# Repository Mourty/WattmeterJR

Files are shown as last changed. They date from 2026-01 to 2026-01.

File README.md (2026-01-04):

# WattmeterJR

This is a smaller cheaper version of the wattmeter described here https://github.com/Mourty/Wattmeter-Project

This version of the measurment board is greatly different than the original and required seperate firmware, but can interface with the service from the original just fine. This version doesn't have the super capacitor and boost converter. It also forgoes the voltage transformer in favor of a voltage divider. All parts that can be surface mount are. This is to save space and cost. The ESP32 used here also isn't a dev module and doesn't have the normal USB interface and requires a seperate UART programming device.

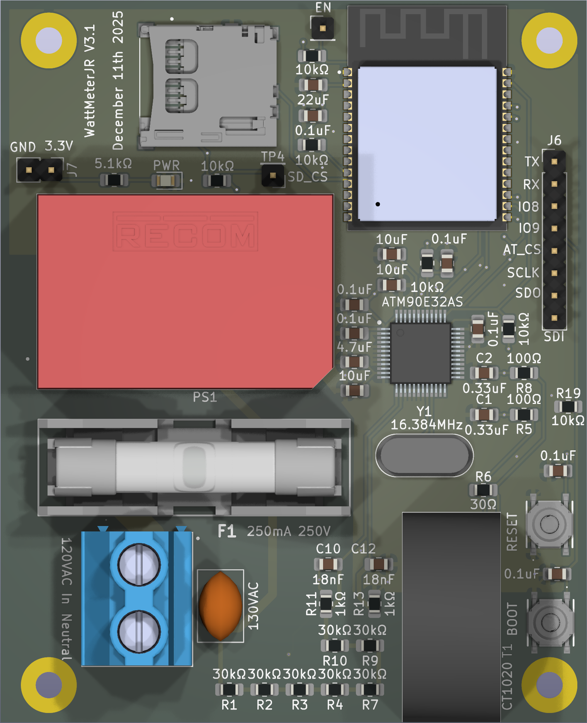
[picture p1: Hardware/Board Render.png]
WattmeterJR Board Render.


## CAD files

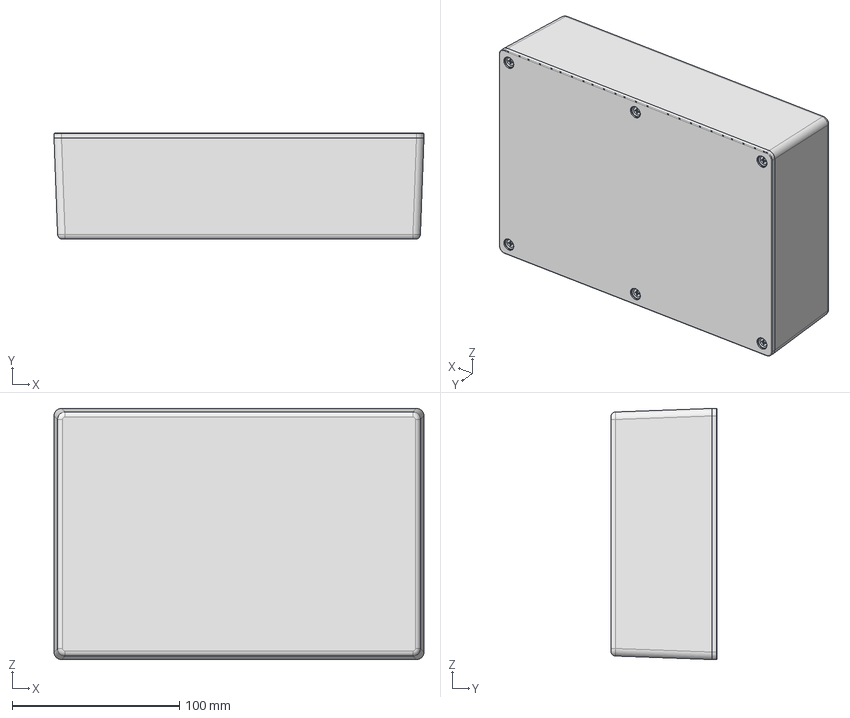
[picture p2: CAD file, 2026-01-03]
Hardware/Circuit and PCB/1591XXFBK.stp
221.0 x 63.5 x 150.0 mm
1591XXF BOX
1591XXF LID
SC500 (screw M3-0.5X 10mm FH) x 6
IN100 (insert M3-0.5X5.75mm BRASS) x 6

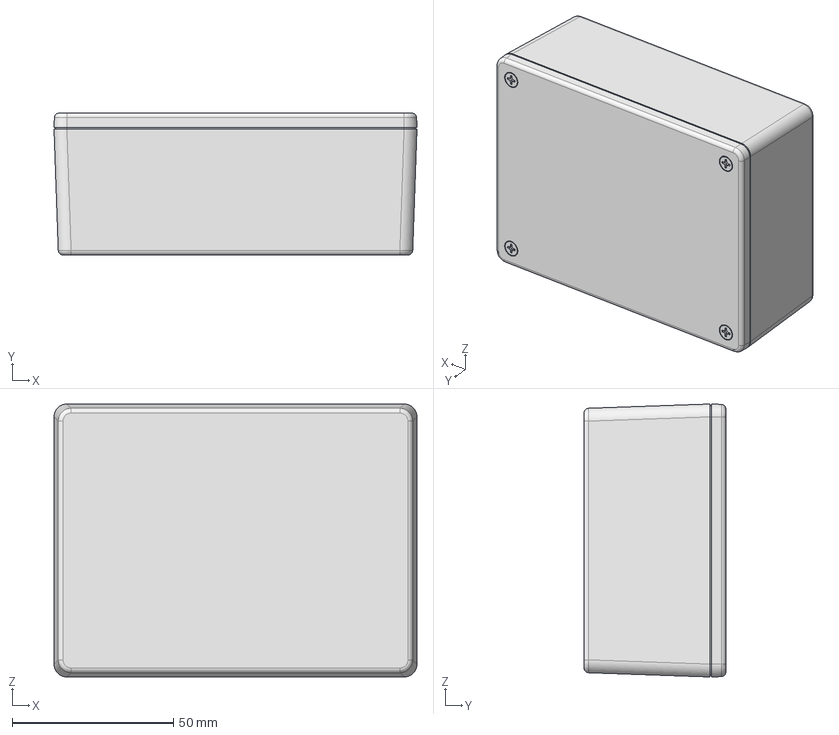
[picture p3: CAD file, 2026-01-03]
Hardware/Solidworks Parts/1591XXSBK.stp
112.5 x 44.0 x 84.6 mm
1591XXS BOX
1591XXS LID
SC500 (screw M3-0.5X 10mm FH) x 4
IN100 (insert M3-0.5X5.75mm BRASS) x 4

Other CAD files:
Hardware/Solidworks Parts/1591XXSBKBody.STP
Hardware/Solidworks Parts/1591XXSBK.SLDASM

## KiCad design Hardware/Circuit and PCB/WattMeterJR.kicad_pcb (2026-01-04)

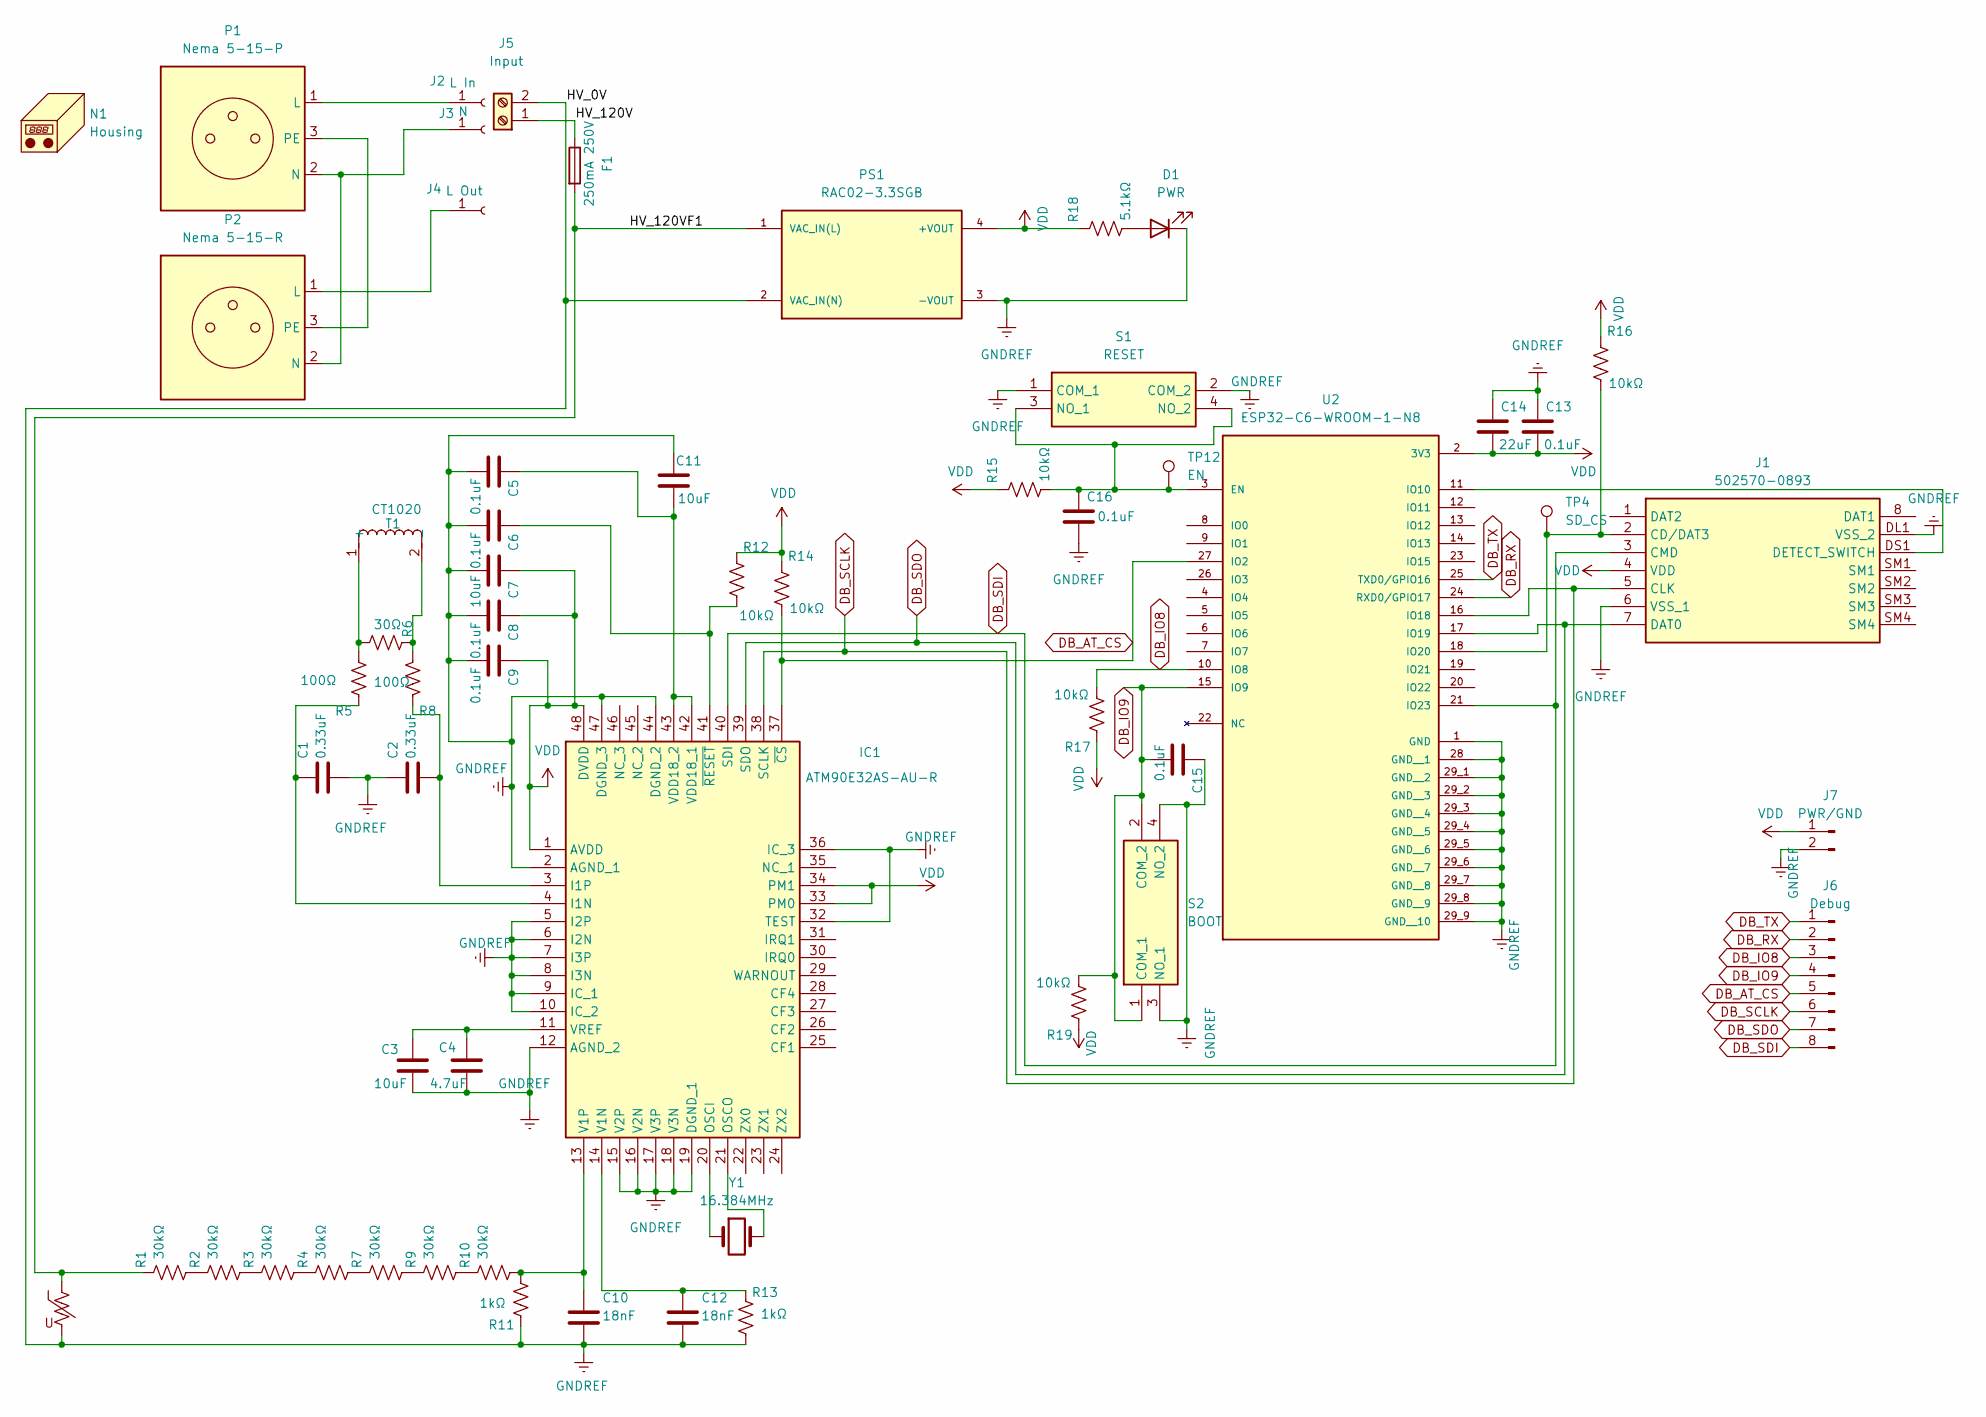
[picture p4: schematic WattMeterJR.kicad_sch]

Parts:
C1, C2: 0.33uF; C_0805_2012Metric_Pad1.18x1.45mm_HandSolder; Mouser# 810-FG18X7R1H334KRT6
C3, C7, C11: 10uF; C_0805_2012Metric_Pad1.18x1.45mm_HandSolder; Mouser# 810-FG18X5R1E106MR00
C4: 4.7uF; C_0805_2012Metric_Pad1.18x1.45mm_HandSolder; Mouser# 810-FG28X5R1E475KRT6
C5, C6, C8, C9, C13, C15, C16: 0.1uF; C_0805_2012Metric_Pad1.18x1.45mm_HandSolder; Mouser# 594-K104K15X7RF5WH5
C10, C12: 18nF; C_0805_2012Metric_Pad1.18x1.45mm_HandSolder; Mouser# 594-K183K10X7RF53H5
C14: 22uF; C_0805_2012Metric_Pad1.18x1.45mm_HandSolder; Mouser# 594-K104K15X7RF5WH5
D1: PWR; LED_0805_2012Metric_Pad1.15x1.40mm_HandSolder
F1: 250mA 250V; 00318231; Mouser# 576-0313.250HXP
IC1: ATM90E32AS-AU-R; QFP50P900X900X120-48N; Mouser# 556-ATM90E32AS-AU-R
J1: 502570-0893; 5025700893; Mouser Part Number 538-502570-0893
J2: L In
J3: N
J4: L Out
J5: Input; CUI_TB005-762-02BE; Mouser# 490-TB005-762-02BE
J6: Debug; PinHeader_1x08_P2.54mm_Vertical
J7: PWR/GND; PinHeader_1x02_P2.54mm_Vertical
N1: Housing; 1591XXSBK
P1: Nema 5-15-P
P2: Nema 5-15-R
PS1: RAC02-3.3SGB; CONV_RAC02-3.3SGB; PARTREV 1
R1, R2, R3, R4, R7, R9, R10: 30kΩ; R_0805_2012Metric_Pad1.20x1.40mm_HandSolder
R5, R8: 100Ω; R_0805_2012Metric_Pad1.20x1.40mm_HandSolder
R6: 30Ω; R_0805_2012Metric_Pad1.20x1.40mm_HandSolder
R11, R13: 1kΩ; R_0805_2012Metric_Pad1.20x1.40mm_HandSolder
R12, R14, R15, R16, R17, R19: 10kΩ; R_0805_2012Metric_Pad1.20x1.40mm_HandSolder
R18: 5.1kΩ; R_0805_2012Metric_Pad1.20x1.40mm_HandSolder
RV1: 130VAC; C_Disc_D8.0mm_W5.0mm_P5.00mm; Mouser# 576-V07E130P
S1: RESET; PTS526SK15SMTR2LFS; Mouser Part Number 611-PTS526SK15SMR2L
S2: BOOT; PTS526SK15SMTR2LFS; Mouser Part Number 611-PTS526SK15SMR2L
T1: CT1020; Manufacturer_Part_Number CS1100L; Digikey# 419-CT1020-ND
TP4: SD_CS; PinHeader_1x01_P2.54mm_Vertical
TP12: EN; PinHeader_1x01_P2.54mm_Vertical
U2: ESP32-C6-WROOM-1-N8; XCVR_ESP32-C6-WROOM-1-N8; PARTREV 1.0
Y1: 16.384MHz; Crystal_HC49-U_Vertical; Mouser# 815-ABL-16.384-B2

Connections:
/HV_120V: F1.1, J5.1
/HV_120VF1: F1.2, PS1.1 (VAC_IN(L)), R1.2, RV1.1
DB_AT_CS: IC1.37 (~CS), J6.5, R14.1, U2.27 (IO2)
DB_IO8: J6.3, R17.1, U2.10 (IO8)
DB_IO9: C15.2, J6.4, R19.1, S2.1 (COM_1), S2.2 (COM_2), U2.15 (IO9)
DB_RX: J6.2, U2.24 (RXD0/GPIO17)
DB_SCLK: IC1.38 (SCLK), J1.5 (CLK), J6.6, U2.16 (IO18)
DB_SDI: IC1.40 (SDI), J1.3 (CMD), J6.8, U2.21 (IO23)
DB_SDO: IC1.39 (SDO), J1.7 (DAT0), J6.7, U2.17 (IO19)
DB_TX: J6.1, U2.25 (TXD0/GPIO16)
GNDREF: C1.2, C2.1, C3.2, C4.2, C5.2, C6.2, C7.1, C8.2, C9.2, C10.2, C11.2, C12.2, C13.1, C14.1, C15.1, C16.2, D1.1 (K), IC1.2 (AGND_1), IC1.5 (I2P), IC1.6 (I2N), IC1.7 (I3P), IC1.8 (I3N), IC1.9 (IC_1), IC1.10 (IC_2), IC1.12 (AGND_2), IC1.15 (V2P), IC1.16 (V2N), IC1.17 (V3P), IC1.18 (V3N), IC1.19 (DGND_1), IC1.32 (TEST), IC1.36 (IC_3), IC1.44 (DGND_2), IC1.47 (DGND_3), J1.6 (VSS_1), J1.DL1 (VSS_2), J5.2, J7.2, PS1.2 (VAC_IN(N)), PS1.3 (-VOUT), R11.2, R13.1, RV1.2, S1.1 (COM_1), S1.2 (COM_2), S2.3 (NO_1), S2.4 (NO_2), U2.1 (GND), U2.28 (GND__1), U2.29_1 (GND__2), U2.29_2 (GND__3), U2.29_3 (GND__4), U2.29_4 (GND__5), U2.29_5 (GND__6), U2.29_6 (GND__7), U2.29_7 (GND__8), U2.29_8 (GND__9), U2.29_9 (GND__10)
unnamed: D1.2 (A), R18.1
unnamed: C1.1, IC1.4 (I1N), R5.2
unnamed: C2.2, IC1.3 (I1P), R8.2
unnamed: IC1.20 (OSCI), Y1.1
unnamed: IC1.21 (OSCO), Y1.2
unnamed: C12.1, IC1.14 (V1N), R13.2
unnamed: C10.1, IC1.13 (V1P), R10.1, R11.1
unnamed: C5.1, C11.1, IC1.42 (VDD18_1), IC1.43 (VDD18_2)
unnamed: C3.1, C4.1, IC1.11 (VREF)
unnamed: C6.1, IC1.41 (~RESET), R12.1
unnamed: J1.2 (CD/DAT3), R16.1, TP4.1, U2.18 (IO20)
unnamed: J1.DS1 (DETECT_SWITCH), U2.11 (IO10)
unnamed: J2.1, P1.1 (L)
unnamed: J3.1, P1.2 (N), P2.2 (N)
unnamed: J4.1, P2.1 (L)
unnamed: P1.3 (PE), P2.3 (PE)
unnamed: R1.1, R2.2
unnamed: R2.1, R3.2
unnamed: R3.1, R4.2
unnamed: R4.1, R7.2
unnamed: R7.1, R9.2
unnamed: R9.1, R10.2
unnamed: C16.1, R15.1, S1.3 (NO_1), S1.4 (NO_2), TP12.1, U2.3 (EN)
unnamed: R5.1, R6.1, T1.1 (+)
unnamed: R6.2, R8.1, T1.2 (-)
VDD: C7.2, C8.1, C9.1, C13.2, C14.2, IC1.1 (AVDD), IC1.33 (PM0), IC1.34 (PM1), IC1.48 (DVDD), J1.4 (VDD), J7.1, PS1.4 (+VOUT), R12.2, R14.2, R15.2, R16.2, R17.2, R18.2, R19.2, U2.2 (3V3)

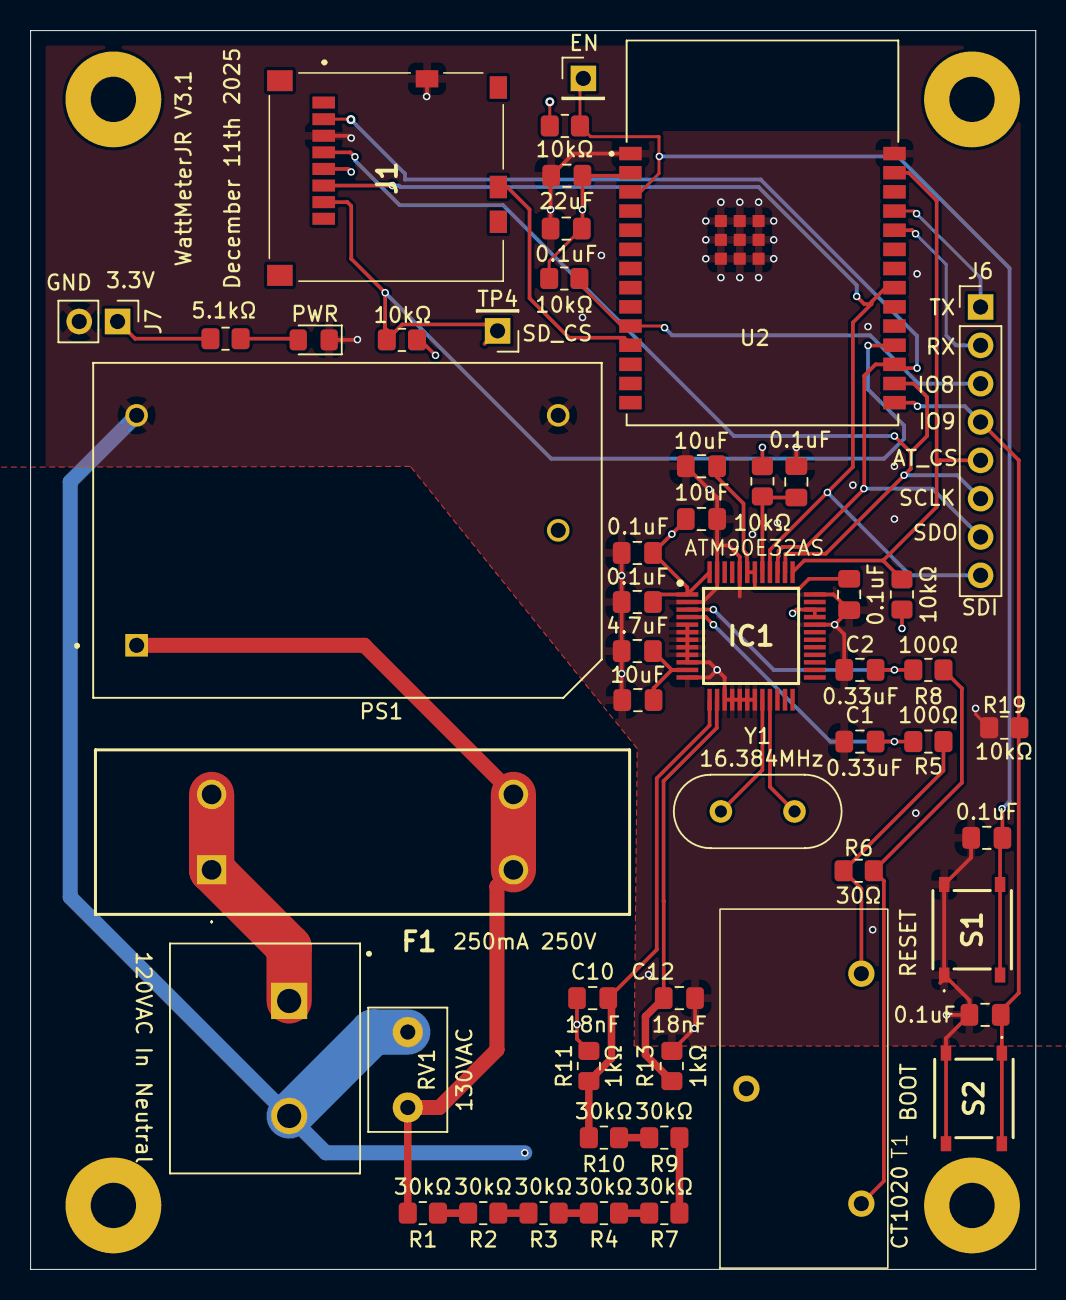
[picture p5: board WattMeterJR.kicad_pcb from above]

Board: 4 copper layers, 66.6 x 82.1 mm, 52 parts (0 on the bottom side), 33 nets.

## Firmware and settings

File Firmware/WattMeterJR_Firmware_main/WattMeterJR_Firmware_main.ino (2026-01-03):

#include <SPI.h>
#include <Wire.h>
#include <WiFi.h>
#include <Timezone.h>
#include <Time.h>
#include "ATM90E32.h"
#include "RegisterAccess.h"
#include "CommandParser.h"
#include "EnergyWebServer.h"
#include "SDCardLogger.h"
#include "SettingsManager.h"
#include "TimeManager.h"
#include "DisplayManager.h"
#include "RebootManager.h"
#include "EnergyAccumulator.h"



// Pin definitions
#define PIN_SPI_M90E32_CS 2  // Chip Select for M90ES32  (Active low)
#define SD_CS_PIN 20         // Chip Select for SD card  (Active Low)
#define SD_CD_PIN 10         // Card Detect
#define SD_WP_PIN 11         // Write Protect
#define PIN_SPI_SCLK 18      // Clock
#define PIN_SPI_MISO 19      // Master In Slave Out
#define PIN_SPI_MOSI 23      // Master Out Slave In
#define PIN_CAP_SENSE 1      // Super cap voltage sense pin
#define I2C_SDA 21           // I2C SDA pin
#define I2C_SDL 22           // I2C SDL pin
#define BUTTON_PIN 3


enum FaultCode {
  FAULT_NONE = 0,
  FAULT_SD_MISSING,
  FAULT_SD_SETTINGS_MISSING,
  FAULT_CHIP_INIT_FAILED,
  FAULT_RTC_INIT_FAILED
};

enum WarningCode {
  WARNING_NONE = 0,
  WARNING_SD_WRITE_PROTECTED
};



//Global Objects
LiquidCrystal_I2C lcd(0x27, 20, 4);
ATM90E32 energyChip(PIN_SPI_M90E32_CS);
RegisterAccess regAccess(energyChip);
TimeManager timeManager;
SDCardLogger sdLogger(regAccess, timeManager, SD_CS_PIN, SD_CD_PIN, SD_WP_PIN);
CommandParser cmdParser(regAccess);
EnergyWebServer EnergyWebServer(regAccess);
SettingsManager settings(regAccess);
EnergyAccumulator energyAccumulator(regAccess);
DisplayManager displayManager(regAccess, timeManager, sdLogger, EnergyWebServer, BUTTON_PIN);
RebootManager rebootManager(timeManager, sdLogger);



// Serial command buffer
String serialCommand = "";
//Heap check timer
static unsigned long lastHeapCheck = 0;

// ================ Settings Helpers ======================

// Apply WiFi settings to web server
bool applyWiFiSettings(const WiFiSettings& wifi) {
  if (wifi.ssid.length() == 0) {
    Serial.println("No WiFi SSID configured");
    return false;
  }

  Serial.println("\nConnecting to WiFi from settings...");
  if (EnergyWebServer.begin(wifi.ssid.c_str(), wifi.password.c_str())) {
    Serial.println("Connected to WiFi from saved settings");
    return true;
  } else {
    Serial.println("Failed to connect to WiFi");
    return false;
  }
}

// Apply RTC calibration settings and timezone
void applyRTCSettings(const RTCCalibrationSettings& rtc, const TimezoneSettings& tz) {
  Serial.println("Applying RTC calibration settings...");
  timeManager.setMinCalibrationDays(rtc.minCalibrationDays);
  timeManager.setCalibrationThreshold(rtc.calibrationThreshold);
  timeManager.setCalibrationEnabled(rtc.autoCalibrationEnabled);
  timeManager.setCalibrationData(rtc.lastCalibrationTime, rtc.currentOffset);

  if (rtc.currentOffset != 0) {
    timeManager.applyCalibrationOffset(rtc.currentOffset);
  }

  // Configure timezone
  char dstAbbrevBuffer[6];
  char stdAbbrevBuffer[6];

  // Copy the abbreviations into static storage
  strncpy(dstAbbrevBuffer, tz.dstAbbrev.c_str(), 5);
  dstAbbrevBuffer[5] = '\0';
  strncpy(stdAbbrevBuffer, tz.stdAbbrev.c_str(), 5);
  stdAbbrevBuffer[5] = '\0';


  TimeChangeRule dstRule = {
    "DST",
    tz.dstWeek,
    tz.dstDow,
    tz.dstMonth,
    tz.dstHour,
    tz.dstOffset
  };

  TimeChangeRule stdRule = {
    "STD",
    tz.stdWeek,
    tz.stdDow,
    tz.stdMonth,
    tz.stdHour,
    tz.stdOffset
  };

  timeManager.setTimezone(dstRule, stdRule);
}


// Sync RTC with NTP if needed
bool syncRTCIfNeeded(const RTCCalibrationSettings& rtc) {
  if (!timeManager.isRTCValid() || !timeManager.hasBeenSynced()) {
    Serial.println("\nSyncing RTC with NTP...");

    if (timeManager.syncFromNTP(rtc.ntpServer.c_str())) {
      RTCCalibrationSettings newSettings = rtc;
      time_t refTime;
      int8_t offset;
      timeManager.getCalibrationData(refTime, offset);
      newSettings.lastCalibrationTime = refTime;
      newSettings.currentOffset = offset;
      settings.setRTCCalibration(newSettings);
      timeManager.setAutoSyncInterval(86400);  // 24 hours
      settings.saveSettings();

      return true;
    }

    return false;
  } else {
    Serial.println("\nRTC already has valid time, skipping NTP sync");
    Serial.print("Current time: ");
    Serial.println(timeManager.getTimeString());

    // Set auto-sync for once per day
    timeManager.setAutoSyncInterval(86400);  // 24 hours
    return true;
  }
}

// Apply data logging settings
void applyDataLoggingSettings(const DataLoggingSettings& log) {
  Serial.println("Applying data logging settings...");

  // Set log fields FIRST (before allocating buffer)
  sdLogger.setLogFields(log.logFields);

  sdLogger.setBufferSize(log.bufferSize);
  sdLogger.setLoggingInterval(log.loggingInterval);
  sdLogger.setPowerLossThreshold(log.powerLossThreshold);
  sdLogger.enablePowerLossDetection(log.enablePowerLossDetection);
}

// Apply display settings
void applyDisplaySettings(const DisplaySettings& disp) {
  Serial.println("Applying display settings...");
  displayManager.setDisplayFields(disp.field0, disp.field1, disp.field2);
  displayManager.setBacklightTimeout(disp.backlightTimeout);
  displayManager.setLongPressTime(disp.longPressTime);
}

// Apply system settings
void applySystemSettings(const SystemSettings& sys) {
  Serial.println("Applying system settings...");
  rebootManager.enable(sys.autoRebootEnabled);
  rebootManager.setRebootInterval(sys.rebootIntervalHours);
  rebootManager.setRebootHour(sys.rebootHour);
}

// Apply all settings (for use after loading or reloading)
void applyAllSettings() {
  Serial.println("\n=== Applying All Settings ===");

  // Apply all registers to ATM90E32
  Serial.println("Applying all registers to ATM90E32...");
  settings.applyAllRegistersToChip();

  // Apply RTC settings AND timezone together
  applyRTCSettings(settings.getRTCCalibration(), settings.getTimezoneSettings());
  // Apply data logging settings
  applyDataLoggingSettings(settings.getDataLoggingSettings());
  // Apply display settings
  applyDisplaySettings(settings.getDisplaySettings());
  // Apply system settings
  applySystemSettings(settings.getSystemSettings());

  // Apply WiFi and sync time if possible
  if (applyWiFiSettings(settings.getWiFiSettings())) {
    syncRTCIfNeeded(settings.getRTCCalibration());

    // Enable logging if RTC is valid
    if (timeManager.isRTCValid()) {
      sdLogger.enableLogging(true);
    }
  }

  Serial.println("=== All Settings Applied ===\n");
}

void applyAllButWIFISettings() {
  Serial.println("\n=== Applying All Settings But WIFI ===");

  // Apply all registers to ATM90E32
  Serial.println("Applying all registers to ATM90E32...");
  settings.applyAllRegistersToChip();

  // Apply RTC settings AND timezone together
  applyRTCSettings(settings.getRTCCalibration(), settings.getTimezoneSettings());
  // Apply data logging settings
  applyDataLoggingSettings(settings.getDataLoggingSettings());
  // Apply display settings
  applyDisplaySettings(settings.getDisplaySettings());
  // Apply system settings
  applySystemSettings(settings.getSystemSettings());

  Serial.println("=== All Settings Applied But WIFI ===\n");
}


// ============== Fault and Warning System ==============





// Global warning state
struct {
  WarningCode activeWarning;
  unsigned long lastWarningDisplay;
  unsigned long warningDisplayInterval;
  unsigned long warningDisplayDuration;
  bool warningDisplayed;
} warningState = { WARNING_NONE, 0, 5000, 3000, false };

// Display a critical fault and halt system
void displayFault(FaultCode fault) {
  lcd.clear();
  lcd.backlight();
  lcd.setCursor(0, 0);
  lcd.print("*** FAULT ***");

  const char* line1 = nullptr;
  const char* line2 = nullptr;

  switch (fault) {
    case FAULT_SD_MISSING:
      line1 = "NO SD CARD FOUND";
      line2 = "Insert SD card";
      break;

    case FAULT_SD_SETTINGS_MISSING:
      line1 = "Settings file";
      line2 = "missing or invalid";
      break;

    case FAULT_CHIP_INIT_FAILED:
      line1 = "ATM90E32 chip";
      line2 = "init failed";
      break;

    case FAULT_RTC_INIT_FAILED:
      line1 = "RTC initialization";
      line2 = "failed";
      break;

    default:
      line1 = "Unknown fault";
      break;
  }

  if (line1) {
    lcd.setCursor(0, 1);
    lcd.print(line1);
  }

  if (line2) {
    lcd.setCursor(0, 2);
    lcd.print(line2);
  }

  // Log to serial
  Serial.println("\n=============================");
  Serial.println("*** CRITICAL FAULT ***");
  if (line1) Serial.println(line1);
  if (line2) Serial.println(line2);
  Serial.println("System will retry in 30 seconds...");
  Serial.println("=============================\n");

  // Display countdown and wait before retry
  for (int countdown = 30; countdown > 0; countdown--) {
    lcd.setCursor(0, 3);
    lcd.print("Retry in ");
    lcd.print(countdown);
    lcd.print(" sec   ");  // Extra spaces to clear previous longer numbers

    Serial.print("Retrying in ");
    Serial.print(countdown);
    Serial.println(" seconds...");

    delay(1000);
  }

  // Clear screen and show rebooting message
  lcd.clear();
  lcd.setCursor(0, 0);
  lcd.print("Rebooting...");
  Serial.println("Rebooting now...");
  delay(1000);

  // Restart the ESP32
  ESP.restart();
}

// Set an active warning (non-blocking)
void setWarning(WarningCode warning) {
  if (warningState.activeWarning != warning) {
    warningState.activeWarning = warning;
    warningState.warningDisplayed = false;
    warningState.lastWarningDisplay = 0;  // Display immediately
    Serial.print("WARNING: ");
    Serial.println(getWarningString(warning));
  }
}

// Clear active warning
void clearWarning() {
  if (warningState.activeWarning != WARNING_NONE) {
    Serial.println("Warning cleared");
    warningState.activeWarning = WARNING_NONE;
    warningState.warningDisplayed = false;
    // Force display update to restore normal view
    displayManager.forceUpdate();
  }
}

// Get warning string for serial output
const char* getWarningString(WarningCode warning) {
  switch (warning) {
    case WARNING_SD_WRITE_PROTECTED:
      return "SD card write protected";
    default:
      return "Unknown warning";
  }
}

// Display warning temporarily on LCD
void displayWarningOnLCD(WarningCode warning) {
  lcd.clear();
  lcd.backlight();
  lcd.setCursor(0, 0);
  lcd.print("!!! WARNING !!!");

  const char* line1 = nullptr;
  const char* line2 = nullptr;
  const char* line3 = nullptr;

  switch (warning) {
    case WARNING_SD_WRITE_PROTECTED:
      line1 = "SD card is";
      line2 = "write protected";
      line3 = "Logging disabled";
      break;

    default:
      line1 = "Unknown warning";
      break;
  }

  if (line1) {
    lcd.setCursor(0, 1);
    lcd.print(line1);
  }

  if (line2) {
    lcd.setCursor(0, 2);
    lcd.print(line2);
  }

  if (line3) {
    lcd.setCursor(0, 3);
    lcd.print(line3);
  }
}

// Update warning display system (call in loop)
void updateWarningDisplay() {
  unsigned long now = millis();

  // No active warning
  if (warningState.activeWarning == WARNING_NONE) {
    warningState.warningDisplayed = false;
    return;
  }

  // Check if it's time to display warning
  if (!warningState.warningDisplayed && (now - warningState.lastWarningDisplay >= warningState.warningDisplayInterval)) {

    // Display the warning
    displayWarningOnLCD(warningState.activeWarning);
    warningState.warningDisplayed = true;
    warningState.lastWarningDisplay = now;
  }

  // Check if it's time to restore normal display
  if (warningState.warningDisplayed && (now - warningState.lastWarningDisplay >= warningState.warningDisplayDuration)) {

    // Restore normal display
    displayManager.forceUpdate();
    warningState.warningDisplayed = false;
  }
}

// Configure warning display timing
void setWarningTiming(unsigned long displayInterval, unsigned long displayDuration) {
  warningState.warningDisplayInterval = displayInterval;
  warningState.warningDisplayDuration = displayDuration;
}


// ================ Setup ======================


void setup() {
  Wire.begin(I2C_SDA, I2C_SDL);

  Serial.begin(115200);

  Serial.println("\n\n=== ATM90E32 Energy Monitor ===");

  // Initialize LCD early so we can display errors
  lcd.init();
  lcd.backlight();
  lcd.setCursor(0, 0);
  lcd.print("Energy Monitor");
  lcd.setCursor(0, 1);
  lcd.print("Initializing...");

  // Initialize hardware
  SPI.begin(PIN_SPI_SCLK, PIN_SPI_MISO, PIN_SPI_MOSI);

  if (!energyChip.begin()) {
    Serial.println("ERROR: Failed to initialize ATM90E32");
    displayFault(FAULT_CHIP_INIT_FAILED);
  }
  Serial.println("ATM90E32 initialized");

  if (!timeManager.begin()) {
    Serial.println("ERROR: Failed to initialize RTC");
    displayFault(FAULT_RTC_INIT_FAILED);
  }

  // Critical: SD card must be present with settings
  if (!sdLogger.begin()) {
    Serial.println("ERROR: SD Card initialization failed");
    displayFault(FAULT_SD_MISSING);
  }

  // SD card is present, but can we load settings?
  if (!settings.loadSettings()) {
    Serial.println("ERROR: Failed to load settings from SD card");
    displayFault(FAULT_SD_SETTINGS_MISSING);
  }

  Serial.println("Settings loaded from SD card");

  // Continue with normal initialization
  displayManager.begin();

  // Apply all loaded settings
  applyAllSettings();

  // Link components to command parser
  cmdParser.setWebServer(&EnergyWebServer);
  cmdParser.setSDLogger(&sdLogger);
  cmdParser.setSettingsManager(&settings);
  cmdParser.setRebootManager(&rebootManager);

  //link settings manager to the webserver
  EnergyWebServer.setSettingsManager(&settings);

  // Initialize energy accumulator
  energyAccumulator.begin(&settings);
  EnergyWebServer.setEnergyAccumulator(&energyAccumulator);
  sdLogger.setEnergyAccumulator(&energyAccumulator);

  // Initialize reboot manager
  rebootManager.begin();

  // Configure warning display (5 seconds between, 3 seconds duration)
  setWarningTiming(5000, 3000);

  Serial.println("\n=== System Ready ===");
  Serial.print("Current time: ");
  Serial.println(timeManager.getTimeString());
  Serial.println("Type 'help' for available commands\n");
  cmdParser.printHelp();
  Serial.print("> ");
}

// ================ Main Loop ======================

void loop() {
  // Update warning display system
  updateWarningDisplay();

  // Handle web server requests
  EnergyWebServer.handleClient();

  // Update TimeManager (handles auto-sync with NTP)
  timeManager.update();

  // Handle SD card logging
  sdLogger.update();

  // Update energy accumulator (reads energy registers, saves periodically)
  energyAccumulator.update();

  // Update display (handles button, backlight, refresh)
  // Only update if no warning is currently being displayed
  if (!warningState.warningDisplayed) {
    displayManager.update();
  }


  // Check for warning condition(s)
  if (sdLogger.isCardPresent() && sdLogger.isWriteProtected()) {
    setWarning(WARNING_SD_WRITE_PROTECTED);
  } else {
    clearWarning();  // Clear if no warnings present
  }


  // Handle serial commands
  while (Serial.available() > 0) {
    char c = Serial.read();

    if (c == '\n' || c == '\r') {
      if (serialCommand.length() > 0) {
        cmdParser.parseCommand(serialCommand);
        serialCommand = "";
        Serial.print("\n> ");
      }
    } else {
      serialCommand += c;
    }
  }

  if (EnergyWebServer.settingsNeedReload()) {
    Serial.println("\n=== Reloading Settings After Remote Change ===");
    applyAllButWIFISettings();
  }

  if (sdLogger.settingsNeedReload()) {
    Serial.println("\n=== Reloading Settings After Power Restoration ===");

    if (settings.loadSettings()) {
      applyAllSettings();
      Serial.println("All settings reloaded and applied");
    } else {
      Serial.println("Failed to reload settings");
    }
  }


  if (millis() - lastHeapCheck >= 60000) {
    Serial.printf("Free heap: %u bytes\n", ESP.getFreeHeap());
    lastHeapCheck = millis();
  }

  // Small delay to prevent watchdog issues
  rebootManager.update();
  delay(1);
}

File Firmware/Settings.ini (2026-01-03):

[WiFi]
SSID=CleverWifiName
Password=SuperSecurePassword

[RTCCalibration]
NTPServer=pool.ntp.org
MinCalibrationDays=1
CalibrationThreshold=5.0
AutoCalibrationEnabled=1
CalibrationEnabled=1
LastCalibrationTime=1762054961
CurrentOffset=36

[Timezone]
; Daylight/Summer Time
DSTAbbrev=CDT
DSTWeek=2  ; 1=First, 2=Second, 3=Third, 4=Fourth, 5=Last
DSTDOW=1  ; 1=Sun, 2=Mon, 3=Tue, 4=Wed, 5=Thu, 6=Fri, 7=Sat
DSTMonth=3  ; 1-12
DSTHour=2  ; 0-23
DSTOffset=-300  ; Minutes from UTC (e.g., -300 for UTC-5)

; Standard Time
STDAbbrev=CST
STDWeek=1
STDDOW=1
STDMonth=11
STDHour=2
STDOffset=-360

[DataLogging]
LoggingInterval=1000
BufferSize=60
PowerLossThreshold=100.0
EnablePowerLossDetection=1
LogFields=UrmsA,IrmsA,PmeanA,QmeanA,SmeanA,Freq

[Display]
Field0=UrmsA
Field1=IrmsA
Field2=PmeanA
BacklightTimeout=30000
LongPressTime=10000

[System]
AutoRebootEnabled=1
RebootIntervalHours=168
RebootHour=9

[Energy_Accumulation]
EnergyReadInterval=20000  ; ms between energy register reads
EnergySaveInterval=600000  ; ms between saves to SD card
AccumulatedEnergyA=0.796860  ; kWh
AccumulatedEnergyB=0.000000  ; kWh
AccumulatedEnergyC=0.000000  ; kWh


[Status_and_Special_Registers]
IA_SRC=0x0	;ADC Input source for phase A current channel (Default: 0x0)
IB_SRC=0x1	;ADC Input source for phase B current channel (Default: 0x1)
IC_SRC=0x2	;ADC Input source for phase C current channel (Default: 0x2)
UA_SRC=0x4	;ADC Input source for phase A voltage channel (Default: 0x4)
UB_SRC=0x5	;ADC Input source for phase B voltage channel (Default: 0x5)
UC_SRC=0x6	;ADC Input source for phase C voltage channel (Default: 0x6)
Sag_Period=0x3F	;Voltage sag period (Default: 0x3F)
PeakDet_period=0x14	;Peak detect period (Default: 0x14)
OVth=0xC000              ; Over voltage threshold (Default: 0xC000)
Zxdis=0x1	;Zero-crossing Signal Disable (Default: 0x1)
ZX0Con=0x0	;ZX 0 Config (Default: 0x0)
ZX1Con=0x0	;ZX 1 Config (Default: 0x0)
ZX2Con=0x0	;ZX 2 Config (Default: 0x0)
ZX0Src=0x0	;ZX 0 Source (Default: 0x0)
ZX1Src=0x0	;ZX 1 Source (Default: 0x0)
ZX2Src=0x0	;ZX 2 Source (Default: 0x0)
SagTh=0x1000             ; Voltage sag threshold (Default: 0x1000)
PhaseLossTh=0x0400       ; Voltage phase loss threshold (Default: 0x0400)
InWarnTh=0xFFFF          ; Neutral current warning threshold (Default: 0xFFFF)
OIth=0xC000              ; Over current threshold (Default: 0xC000)
FreqLoTh=0x170C          ; Frequency low threshold (Default: 0x170C)
FreqHiTh=0x17D4          ; Frequency high threshold (Default: 0x17D4)
IRQ1_OR=0x0	;IRQ1 OR with IRQ0 (Default: 0)
WARN_OR=0x0	;WARN OR with IRQ0 (Default: 0)


[Configuration_Registers]
PL_Constant=0x0861C468          ;PL constant (Default: 0x0861C468)
EnPC=0x1	;Phase C all-Phase Sum energy enable (Default: 0x1)
EnPB=0x1	;Phase B all-Phase Sum energy enable (Default: 0x1)
EnPA=0x1	;Phase A all-Phase Sum energy enable (Default: 0x1)
ABSEnP=0x0	;Active Power summing method (Default: 0x0)
ABSEnQ=0x0	;Reactive Power summing method (Default: 0x0)
CF2varh=0x1	;CF2 Pin Source (Default: 0x1)
3P3W=0x0	;3 or 4 wire 3 phase mode	 (Default: 0x0)
didtEn=0x0	;Enable Integrator for didt current sensor (Default: 0x0)
HPFoff=0x0	;Disable HPF Signal processing (Default: 0x0)
Freq60Hz=0x1	;Grid frequency flag (Default: 0x1)
PGA_GAIN=0x0000	;PGA Gain Config (Default 0x0000)
PStartTh=0x0000          ; Active startup power threshold (Default: 0x0000)
QStartTh=0x0000          ; Reactive startup power threshold (Default: 0x0000)
SStartTh=0x0000          ; Apparent startup power threshold (Default: 0x0000)
PPhaseTh=0x0000          ; Phase active power startup threshold (Default: 0x0000)
QPhaseTh=0x0000          ; Phase reactive power startup threshold (Default: 0x0000)
SPhaseTh=0x0000          ; Phase apparent power startup threshold (Default: 0x0000)

[Calibration_Registers]
PoffsetA=0x0000          ; Phase A active power offset (Default: 0x0000)
QoffsetA=0x0000          ; Phase A reactive power offset (Default: 0x0000)
PoffsetB=0x0000          ; Phase B active power offset (Default: 0x0000)
QoffsetB=0x0000          ; Phase B reactive power offset (Default: 0x0000)
PoffsetC=0x0000          ; Phase C active power offset (Default: 0x0000)
QoffsetC=0x0000          ; Phase C reactive power offset (Default: 0x0000)
PQGainA=0xFF8E           ; Phase A energy calibration gain (Default: 0x0000)
PhiA=0x0000              ; Phase A energy calibration phase angle (Default: 0x0000)
PQGainB=0x0000           ; Phase B energy calibration gain (Default: 0x0000)
PhiB=0x0000              ; Phase B energy calibration phase angle (Default: 0x0000)
PQGainC=0x0000           ; Phase C energy calibration gain (Default: 0x0000)
PhiC=0x0000              ; Phase C energy calibration phase angle (Default: 0x0000)
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

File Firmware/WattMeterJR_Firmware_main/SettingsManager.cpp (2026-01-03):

#include "SettingsManager.h"

const char* SettingsManager::SETTINGS_FILE = "/settings.ini";

SettingsManager::SettingsManager(RegisterAccess& regAccess)
: _regAccess(regAccess) {
    // Initialize WiFi with defaults
    _wifi.ssid = "";
    _wifi.password = "";
    
    // Default RTC calibration settings
    _rtcCalibration.ntpServer = "pool.ntp.org";
    _rtcCalibration.minCalibrationDays = 1;
    _rtcCalibration.calibrationThreshold = 5.0;
    _rtcCalibration.autoCalibrationEnabled = true;
    _rtcCalibration.lastCalibrationTime = 0;
    _rtcCalibration.currentOffset = 0;
    _rtcCalibration.calibrationEnabled = true;
    
    // Default timezone settings (US Central Time)
    _timezone.dstAbbrev = "CDT";
    _timezone.dstWeek = 2;           // Second week
    _timezone.dstDow = 1;            // Sunday (using Timezone library convention: 1=Sun)
    _timezone.dstMonth = 3;          // March
    _timezone.dstHour = 2;           // 2 AM
    _timezone.dstOffset = -300;      // UTC-5 hours
    
    _timezone.stdAbbrev = "CST";
    _timezone.stdWeek = 1;           // First week
    _timezone.stdDow = 1;            // Sunday
    _timezone.stdMonth = 11;         // November
    _timezone.stdHour = 2;           // 2 AM
    _timezone.stdOffset = -360;      // UTC-6 hours

    // Data logging defaults
    _dataLogging.loggingInterval = 1000;           // 1 second
    _dataLogging.bufferSize = 60;                  // 60 readings
    _dataLogging.powerLossThreshold = 100.0;       // 100V
    _dataLogging.enablePowerLossDetection = true;
    _dataLogging.logFields = "UrmsA,IrmsA,PmeanA,SmeanA,QmeanA,Freq";

    // Display defaults
    _display.field0 = "UrmsA";
    _display.field1 = "IrmsA";
    _display.field2 = "PmeanA";
    _display.backlightTimeout = 30000;  // 30 seconds
    _display.longPressTime = 10000;     // 10 seconds

    // System defaults
    _system.autoRebootEnabled = true;
    _system.rebootIntervalHours = 168;  // 1 week
    _system.rebootHour = 3;              // 3 AM

    // Status and Special Registers defaults
    _statusAndSpecialRegisters.IA_SRC = 0x0;
    _statusAndSpecialRegisters.IB_SRC = 0x1;
    _statusAndSpecialRegisters.IC_SRC = 0x2;
    _statusAndSpecialRegisters.UA_SRC = 0x4;
    _statusAndSpecialRegisters.UB_SRC = 0x5;
    _statusAndSpecialRegisters.UC_SRC = 0x6;
    _statusAndSpecialRegisters.Sag_Period = 0x3F;
    _statusAndSpecialRegisters.PeakDet_period = 0x14;
    _statusAndSpecialRegisters.OVth = 0xC000;
    _statusAndSpecialRegisters.Zxdis = 0x1;
    _statusAndSpecialRegisters.ZX0Con = 0x0;
    _statusAndSpecialRegisters.ZX1Con = 0x0;
    _statusAndSpecialRegisters.ZX2Con = 0x0;
    _statusAndSpecialRegisters.ZX0Src = 0x0;
    _statusAndSpecialRegisters.ZX1Src = 0x0;
    _statusAndSpecialRegisters.ZX2Src = 0x0;
    _statusAndSpecialRegisters.SagTh = 0x1000;
    _statusAndSpecialRegisters.PhaseLossTh = 0x0400;
    _statusAndSpecialRegisters.InWarnTh = 0xFFFF;
    _statusAndSpecialRegisters.OIth = 0xC000;
    _statusAndSpecialRegisters.FreqLoTh = 0x170C;
    _statusAndSpecialRegisters.FreqHiTh = 0x17D4;
    _statusAndSpecialRegisters.IRQ1_OR = 0x0;
    _statusAndSpecialRegisters.WARN_OR = 0x0;

    // Configuration Registers defaults
    _configurationRegisters.PL_Constant = 0x0861C468;
    _configurationRegisters.EnPC = 0x1;
    _configurationRegisters.EnPB = 0x1;
    _configurationRegisters.EnPA = 0x1;
    _configurationRegisters.ABSEnP = 0x0;
    _configurationRegisters.ABSEnQ = 0x0;
    _configurationRegisters.CF2varh = 0x1;
    _configurationRegisters._3P3W = 0x0;
    _configurationRegisters.didtEn = 0x0;
    _configurationRegisters.HPFoff = 0x0;
    _configurationRegisters.Freq60Hz = 0x1;
    _configurationRegisters.PGA_GAIN = 0x0000;
    _configurationRegisters.PStartTh = 0x0000;
    _configurationRegisters.QStartTh = 0x0000;
    _configurationRegisters.SStartTh = 0x0000;
    _configurationRegisters.PPhaseTh = 0x0000;
    _configurationRegisters.QPhaseTh = 0x0000;
    _configurationRegisters.SPhaseTh = 0x0000;

    // Calibration Registers defaults (energy calibration)
    _calibrationRegisters.PoffsetA = 0x0000;
    _calibrationRegisters.QoffsetA = 0x0000;
    _calibrationRegisters.PoffsetB = 0x0000;
    _calibrationRegisters.QoffsetB = 0x0000;
    _calibrationRegisters.PoffsetC = 0x0000;
    _calibrationRegisters.QoffsetC = 0x0000;
    _calibrationRegisters.PQGainA = 0x0000;
    _calibrationRegisters.PhiA = 0x0000;
    _calibrationRegisters.PQGainB = 0x0000;
    _calibrationRegisters.PhiB = 0x0000;
    _calibrationRegisters.PQGainC = 0x0000;
    _calibrationRegisters.PhiC = 0x0000;
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

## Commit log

2026-01-04 Add pullup for GPIO9
    [WattMeterJR.kicad_pcb, WattMeterJR.kicad_sch]
2026-01-04 fix board render
